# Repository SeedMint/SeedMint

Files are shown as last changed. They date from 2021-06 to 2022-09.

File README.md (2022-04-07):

# SeedMint
[DONATE](https://permissionlessstore.duckdns.org:57800/apps/4U7dYjY3Po74d5rREmCaG5ngVtTc/pos)

### INTRODUCTION

#### SEEDMINT is a FREE OPEN SOURCE HARDWARE (FOSH) Product.  
  
Technical drawings, material specifications and information regarding standard parts can be found in the designated folder.  
  
Adequate personal bitcoin security is a daunting challenge - one that will not forgive many mistakes. Every user’s situation regarding technical understanding and personal priorities, threat model and risk tolerance is fundamentally unique which renders generalized advice insufficient at best, dangerously confusing at worst.  
To achieve a level of security you can feel comfortable with you must find the right trade-off between cost, privacy, complexity, and failure tolerance.  
We cannot tell you what is best for your individual situation, but we can do our best to provide tools to aid you on your journey. The first of these tools is the SEEDMINT.
  
### PURPOSE
  
The SEEDMINT is a tool designed to easily secure your 12 or 24 bitcoin backup words (mnemonic seed phrase) on highly durable V4A stainless steel washers.
Using the included punches (4mm numbers & 2mm letters/numbers) you can stamp the index number (01 to 24) as well as the significant characters (first four letters) of each word onto one washer. This will result in 12 or 24 stamped washers.  
Additional washers can be stamped with any relevant information you would like to secure in combination with your seed. This additional information may include but is not limited to: master fingerprint, derivation path, wallet name, passphrase, multisig scheme,...  
  The stamped washers can be held on a 316L stainless steel screw, fastened by a self-locking nut and stored in a secure location as an ultimate backup.
The above description is the use case we envisioned as a basis for the design of the SEEDMINT and is merely a recommendation. At the end of the day, it is up to you which information you would like to stamp on the washers and how you choose to store them.

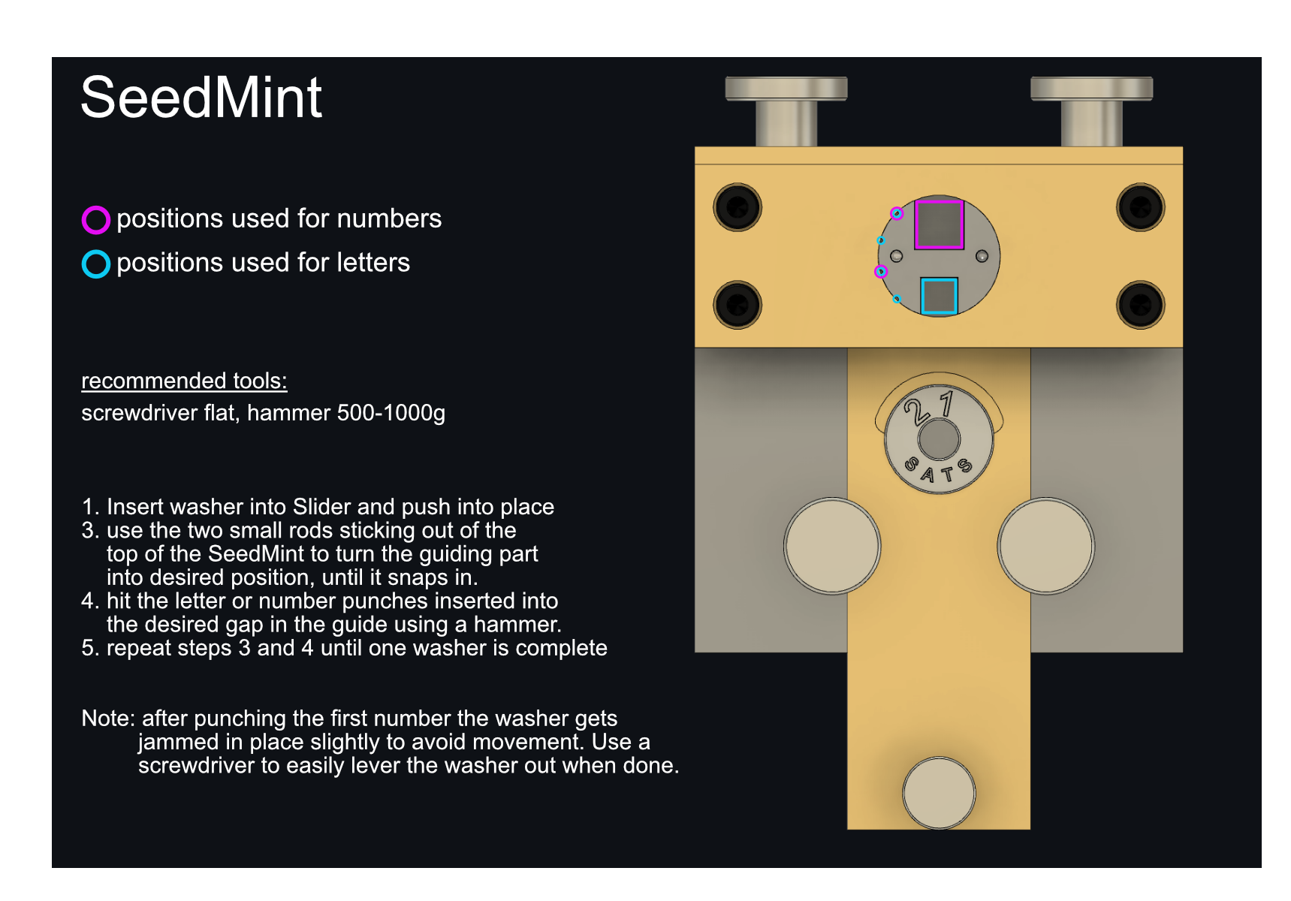
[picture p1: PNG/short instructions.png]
SeedMint


Click "view code" on the Top to see all files

In the [CAD](https://github.com/SeedMint/SeedMint/tree/main/CAD "Drawings and 3D Model") folder you find the complete design in different format types .zip for Inventor 2019 and .f3z for [Autodesk Fusion 360](https://www.autodesk.de/campaigns/education/fusion360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 "Autodesk Fusion 360") (which doesnt cost anything for personal use)

Here you find the [PDF](https://github.com/SeedMint/SeedMint/tree/main/PDF) drawings of the single pieces and a parts list.

This are links to the [letter](https://www.amazon.de/gp/product/B01BTTMEJU/ref=ppx_yo_dt_b_asin_title_o08_s00?ie=UTF8&psc=1) and [number](https://www.amazon.de/Turnus-330-004-TURNUS-0007697220004-Schlagbuchstaben-Nummern/dp/B00D17RJ7Q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) stamps used in the current Design

Parts to buy: (just paste the description into a search engine to find local sources)

<table>
  <thead>
    <tr>
      <th>Amount</th>
      <th>Description</th>     
    </tr>
  </thead>
  <tbody>
    <tr>
      <td>4</td>
      <td>cylinder head screw DIN 912 M4x20</td>    
    </tr>
    <tr>
      <td>2</td>
      <td>flat knurled screw M4x10</td>
    </tr>
     <tr>
      <td>2</td>
      <td>high knurled screw M5X12</td>
    </tr>
     <tr>
      <td>2</td>
      <td>parallel pin ISO 8734 2m6x20 blank</td>
        <tr>
      <td>1</td>
      <td>high knurled screw M3 (thread shortened)</td>
    </tr>
     <tr>
      <td>1</td>
      <td>spring plunger with thread locking GN 615.3-M4-k-PFB</td>
    </tr>
     <tr>
      <td>1</td>
      <td>parallel pin ISO 8734 3m6x12 blank</td>
    </tr>
     <tr>
      <td>min. 24</td>
      <td>washer DIN 9021 6.4 A4(316L) or titanium grade 2</td>
    </tr>
     <tr>
      <td>1 set</td>
      <td>number punches 4mm</td>
    </tr>
     <tr>
      <td>1 set</td>
      <td>letter punches 2mm</td>
    </tr>
  </tbody>
</table>

The "original" **SeedMint** was tinkered without any references or drawings at all. Just for the love of handcrafiting things that I consider useful.
But only after somebody asked me, if i would make plans for such a Jig available,  so I thought if only one person would get value from this, it would have been worth while making those plans. This has also been the first time I have heared about [Blockmit](https://blockmit.com/english/guides/diy/make-cold-wallet-washers/ "blockmit.com") - quite ignorant as I'll admit..

The Jig is intended to be used with 2-3mm letter- and 4mm number punches on an M6 stainless steel washer with an outer diameter of 18mm.
Just use a screw and a nut to hold them together.
More solutions will follow.

Any contribution and/or feedback is greatly appreciated.

follow us [@SeedMint21](https://twitter.com/SeedMint21) on twitter for updates 
<!--
**SeedMint/SeedMint** is a ✨ _special_ ✨ repository because its `README.md` (this file) appears on your GitHub profile.

Here are some ideas to get you started:

- 🔭 I’m currently working on ...
- 🌱 I’m currently learning ...
- 👯 I’m looking to collaborate on ...
- 🤔 I’m looking for help with ...
- 💬 Ask me about ...
- 📫 How to reach me: ...
- 😄 Pronouns: ...
- ⚡ Fun fact: ...
-->

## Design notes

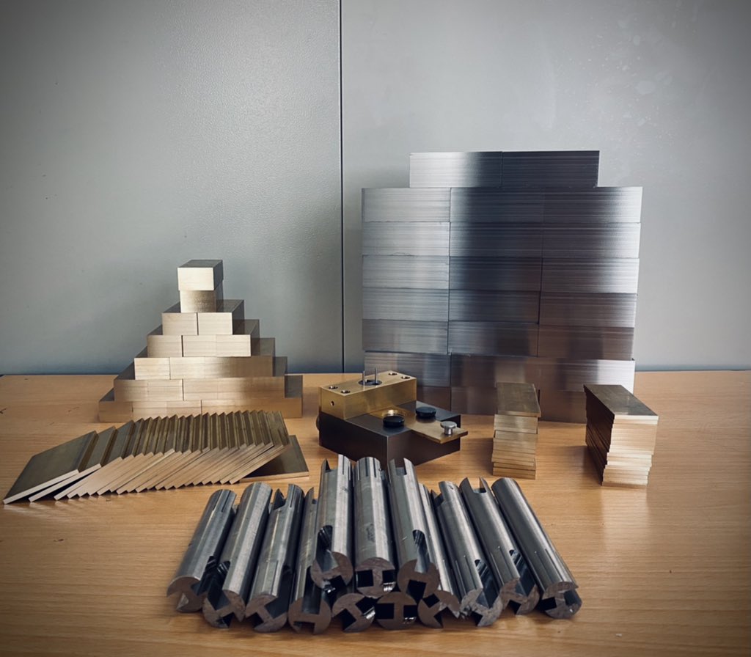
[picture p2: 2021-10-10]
PNG/4161E84F-398B-41A6-904F-D0B08AE500F2.jpeg

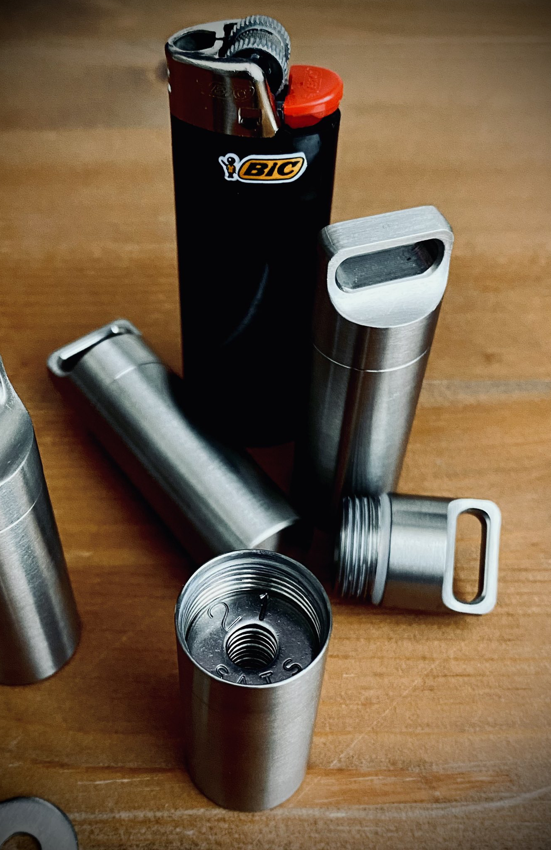
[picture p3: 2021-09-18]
PNG/pill.jpg

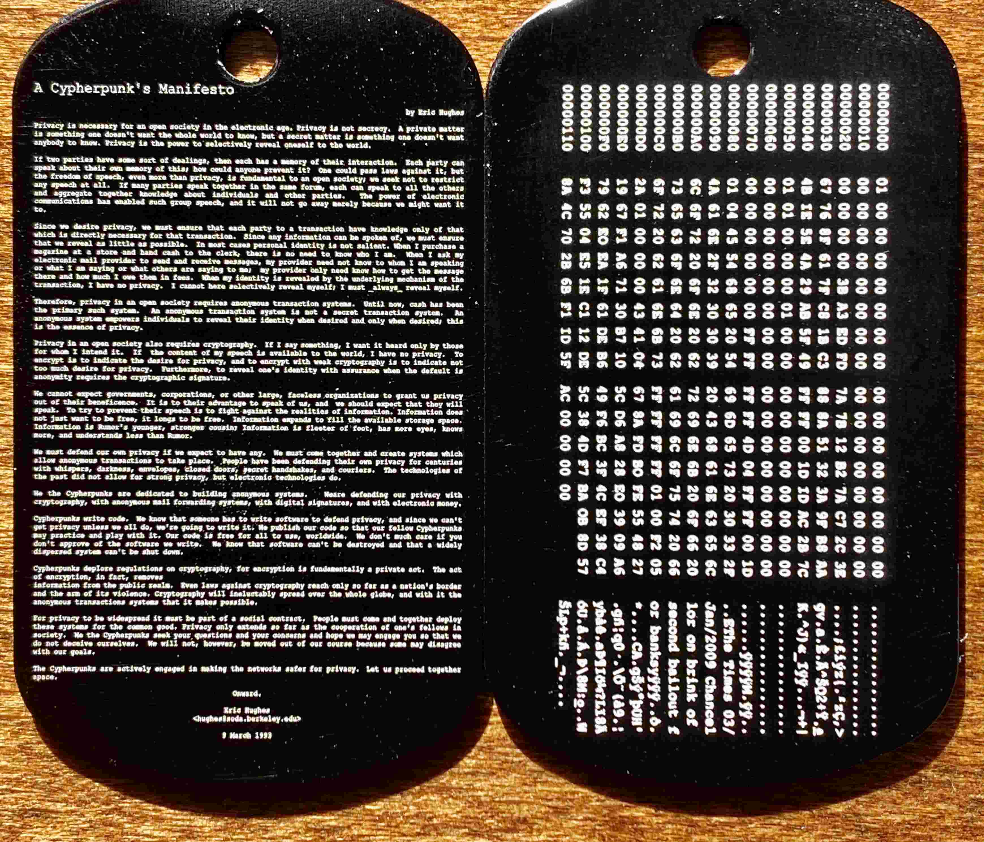
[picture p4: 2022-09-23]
PNG/manifesto_genesis.jpg

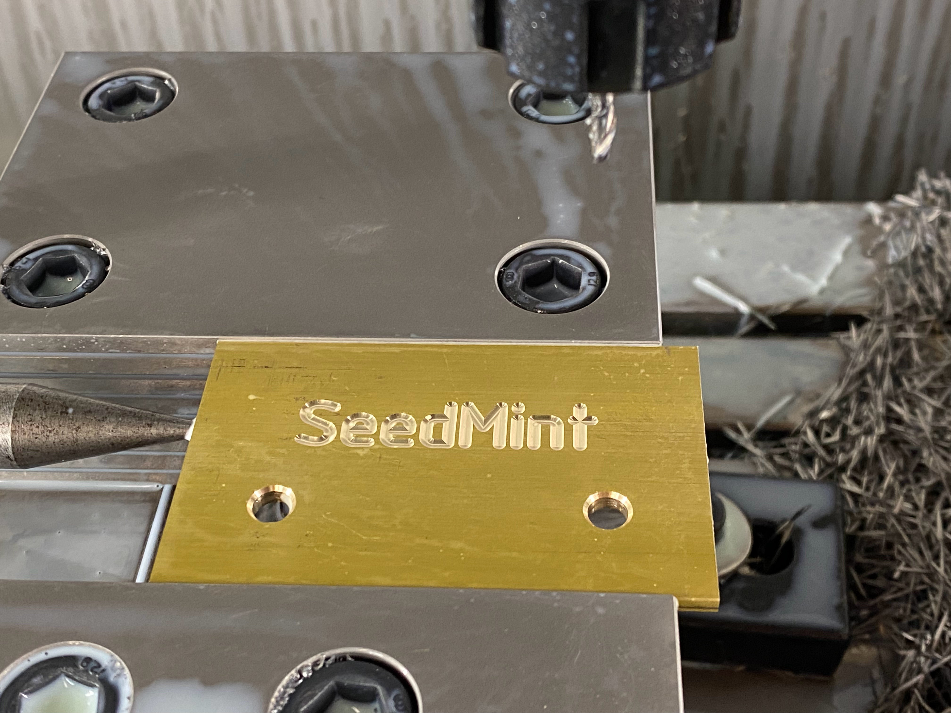
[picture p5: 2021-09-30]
PNG/FP.jpg

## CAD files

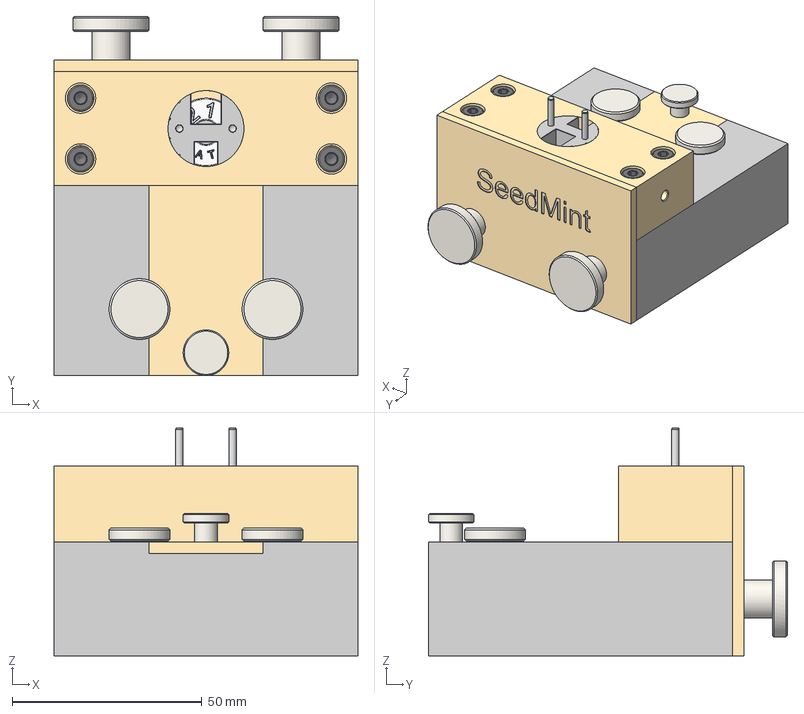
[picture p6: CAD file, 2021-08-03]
CAD/SeedMint Assembly.step
80.0 x 94.5 x 60.0 mm
Faceplate
Base
Slider
Retainer
Guide
HI_WUERTH 00824 20 cylinder head screw DIN 912 M4x20 8.8 BLK x 4
_Knurled screw DIN 464-M3-6-ZB
_Flat knurled screw DIN 653-M4-10-ZB x 2
_Knurled screw DIN 464-M5-12-ZB x 2
parallel pin ISO 8734 3m6x12 blank
parallel pin ISO 8734 2m6x20 Blank x 2
Spring plunger with thread locking GN 615.3-M3-K-PFB
washer DIN 9021 6.4 A4

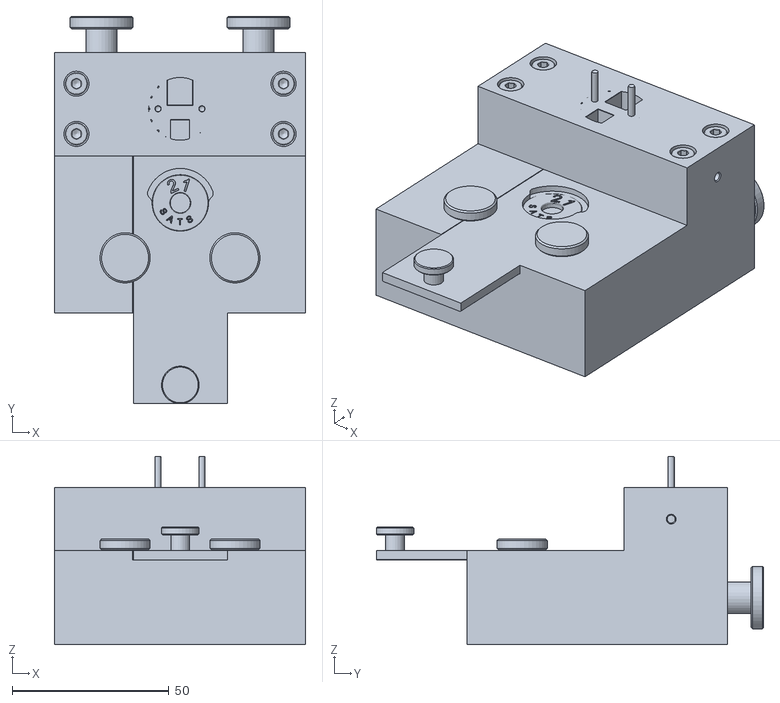
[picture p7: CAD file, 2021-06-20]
CAD/SeedMint.stl
80.0 x 123.5 x 60.0

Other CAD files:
CAD/Assembly v1.dwg
CAD/Base Drawing a3 v1.dwg
CAD/Slider Drawing A3 for CNC v1.dwg
CAD/Guide Drawing A4 v1.dwg
CAD/Faceplate Drawing A3 v1.dwg
CAD/Retainer Drawing A3 v1.dwg
CAD/SeedMint assembly.f3z

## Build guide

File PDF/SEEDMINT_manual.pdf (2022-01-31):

# SEEDMINT

## MANUAL

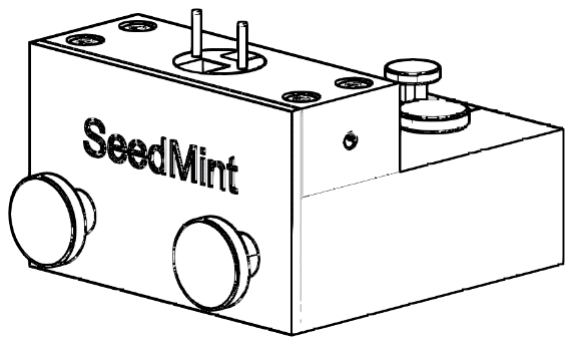
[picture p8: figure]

- 1 -

### CONTENT

INTRODUCTION | 2-3
PURPOSE | 4-5
PACKAGE CONTENT | 6
SEEDMINT - PART LIST | 7-10
ASSEMBLY | 11-12
HANDLING | 13-16
CARE | 17-18
PRIVACY POLICY | 19
CONTACT | 20 - 23

- 2 -

### INTRODUCTION

This is a 100% private offering. No safety labels, no security checks, no warranty, no refund, no guarantees - just two plebs' word.

SEEDMINT is a FREE OPEN SOURCE HARDWARE (FOSH) Product published under the MIT license. Technical drawings, material specifications and information regarding standard parts as well as this manual can be found at:

https://github.com/SeedMint

- 3 -

Adequate personal bitcoin security is a daunting challenge - one that will not forgive many mistakes. Every user’s situation regarding technical understanding and personal priorities, threat model and risk tolerance is fundamentally unique which renders generalized advice insufficient at best, dangerously confusing at worst.

To achieve a level of security you can feel comfortable with you must find the right trade-off between cost, privacy, complexity, and failure tolerance.

We cannot tell you what is best for your individual situation, but we can do our best to provide tools to aid you on your journey. The first of these tools is the SEEDMINT.

- 4 -

### PURPOSE

The SEEDMINT is a tool designed to easily secure your 12 or 24 bitcoin backup words (mnemonic seed phrase) on highly durable V4A stainless steel washers.

Using the included punches (4mm numbers & 2mm letters/numbers) you can stamp the index number (01 to 24) as well as the significant characters (first four letters) of each word onto one washer. This will result in 12 or 24 stamped washers.

Additional washers can be stamped with any relevant information you would like to secure in combination with your seed. This additional information may include but is not limited to: seed creation date, seed creation block hight, master fingerprint,

- 5 -

derivation path, wallet name, passphrase, multisig scheme, or xpub. The stamped washers can be held on a V4A stainless steel screw, fastened by a self-locking nut (included in the package) and stored in a secure location as an ultimate backup.

The above description is the use case we envisioned as a basis for the design of the SEEDMINT and is merely a recommendation. At the end of the day, it is up to you which information you would like to stamp on the washers and how you choose to store them.

- 6 -

### PACKAGE CONTENT

1x | SEEDMINT
1x | Set of 4mm number punches
1x | Set of 2mm number punches
1x | Set of 2mm letter punches
1x | Silicon oil 65ml
210x | M6 V4A stainless steel washers
3x | M6x60 V4A stainless steel screws
3x | M6x30 V4A stainless steel screws
6x | M6 V4A stainless steel self-locking bolt

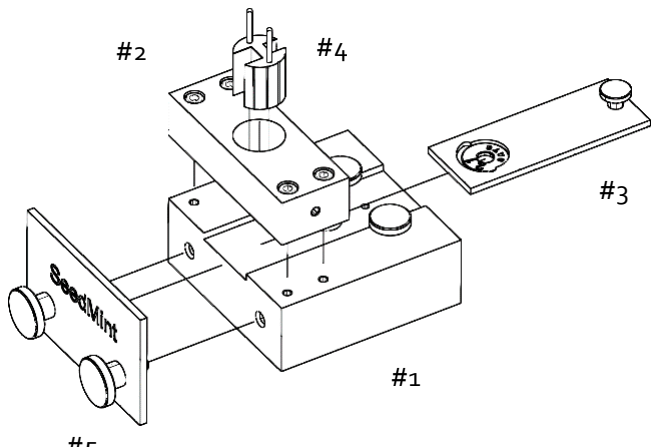
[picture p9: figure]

- 7 -

### SEEDMINT - PART LIST

Milled parts:
#1 BASE

#2 RETAINER

#3 SLIDER

#4 GUIDE

#5 FACEPLATE

#5

- 8 -

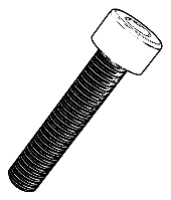
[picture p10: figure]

Standard parts:
4x | Cylinder head screw DIN 912 M4x20

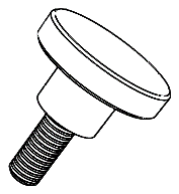
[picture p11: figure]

2x | Flat knurled screw M4x10
2x | High knurled screw M5X12

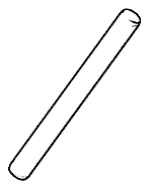
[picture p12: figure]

2x | Parallel pin ISO 8734 2m6x20 blank

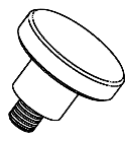
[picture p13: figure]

1x | High knurled screw M3 (shortened)

- 9 -

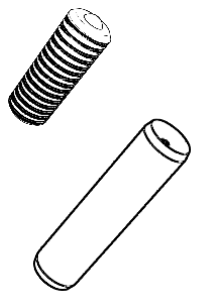
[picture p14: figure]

1x | Spring plunger with thread locking GN615.3-M4-k-PFB
1x | Parallel pin ISO 8734 3m6x12 blank

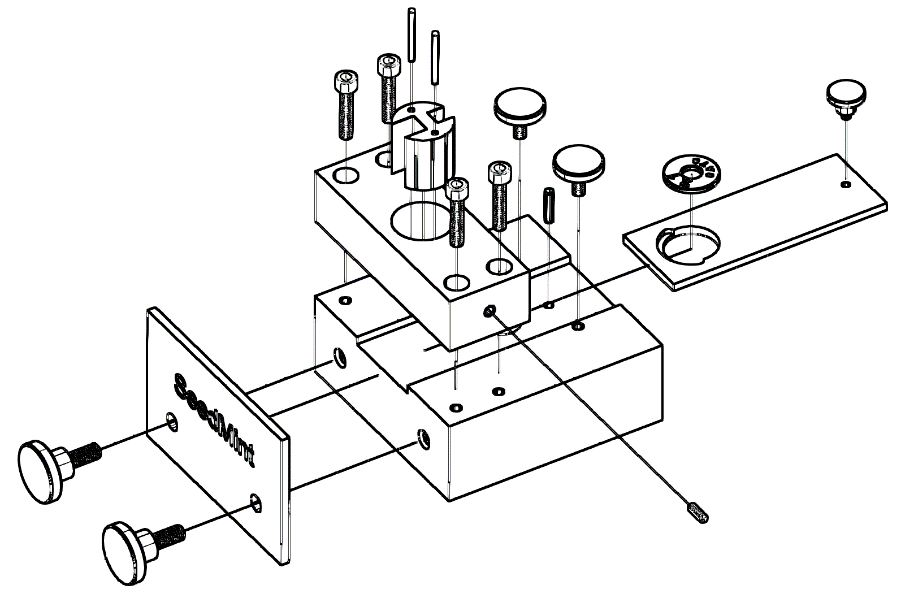
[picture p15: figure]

- 10

- 11 -

### ASSEMBLY

The SEEDMINT will be shipped in a semi-assembled state. The GUIDE is separate within the package. Place the SEEDMINT on a flat surface and insert the GUIDE into the central hole in the RETAINER with the larger cut-out facing left and the two pins facing upwards. After inserting the GUIDE slowly turn it clockwise by applying light torque to the two pins. You will feel four rachet positions while turning 180°. These are the four 4mm and four 2mm defined stamping positions visualized on the next page.

Check that all knurled screws are securely fastened.

Your SEEDMINT is now ready for use.

- 12 -

Stamping positions:

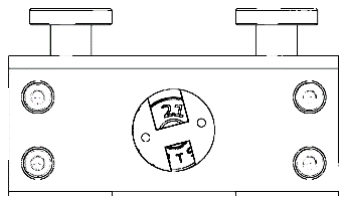
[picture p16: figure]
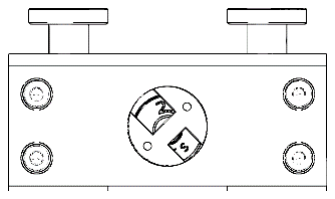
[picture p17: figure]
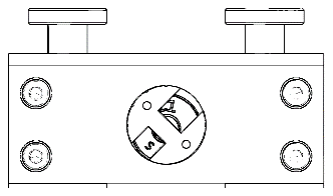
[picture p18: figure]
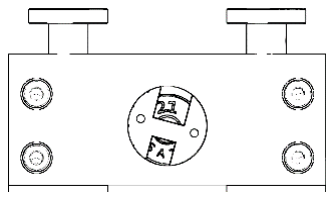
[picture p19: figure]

Deviating from these four positions is possible for a custom layout but not advised for accurately reproducible results.

2 Pos. 1 | Pos. 2
Pos. 3 | Pos. 4

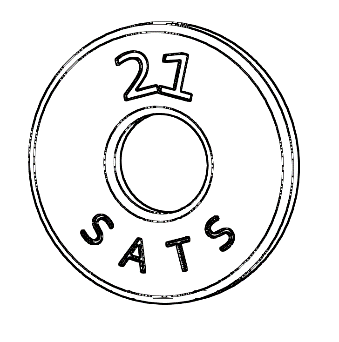
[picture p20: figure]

- 13 -

### HANDLING

Let’s start off with a test run: this is what the test washer will look like if we were successful in writing a comprehensive manual:

1. Before you start you will need a firm, flat surface to place your SEEDMINT on, a hammer, as well as all parts included in the package.

- 14 -
2. You can start by pulling back the SLIDER and inserting a washer with the rounded edges facing upwards. By pushing the SLIDER back under the RETAINER, the washer will be correctly positioned under the GUIDE.
3. Rotate the GUIDE to position 2 and insert the number “2” 4mm punch into the large cut-out (if you would prefer the numbers to be stamped with a small offset you can also choose position 1 instead).
4. Rest the palm of your left hand (right if you are lefthanded) on the knurled screw on the SLIDER to ensure the SLIDER does not move and stabilize the punch between your thumb and forefinger. Push the punch down against the washer.
5. Now the moment you have been waiting for: We know you really want to WHACK IT but start off with moderate force.

- 15 -

NOTE: It is not advised to stamp the same character twice in the same position on the same washer as this can damage the punches. If you are not happy with the level of penetration you can crank it up on the next washer.

6. Extract the punch and rotate the GUIDE into position 3 and repeat as from bullet point 4. Using the number “1” 4mm punch.
7. Once the index number is stamped, extract the punch, rotate the GUIDE to position 4, insert the first 2mm letter punch “S” and hit it.
8. Positions 3, 2, 1 follow with the 2mm letter punches “A”, “T”, “S” respectively.
9. Pull back the SLIDER and retrieve the washer using a flat headed screwdriver or just flipping the SEEDMINT on its head.
10. Congrats, your first stamped washer is complete!

- 16 -

After you’ve stamped a few washers, you’ll get a feel for the process and start to produce consistent results. Once you feel comfortable it’s time to start with an actual seed. For this you can either retrieving a backup of an old seed or securely create a new one and write it down on a piece of paper with the index numbers leading each word. Take the time to double check each word!

01 | ACTION | [...]
02 | BOSS | 23 | WILL
[...] | | 24 | WISH
11. Write down all information you’d like to stamp additionally.
12. Be diligent and perfectionistic about your work. You’ll thank yourself later.

- 17 -

### CARE

The SEEDMINT is a tool, no doubt about it. Beautiful, absolutely, but made to be used. She likes it rough, but she’ll need some love and care along the way.

To prevent highly oxidated surfaces and ensure ease of use you should store the SEEDMINT in a dry environment.

Included in the package is a bottle of silicon oil. Before first use after a long time in storage, apply a thin oil film to the contact surfaces between the GUIDE and the RETAINER using a cotton cloth.

A spring plunger is screwed into the RETAINER to provide defined stamping positions to the GUIDE. We carefully adjusted the plunger during assembly to apply the correct amount of force for an easy

- 18 -

but well-defined feel. The correct position over time was ensured by using thread locking glue (LOCTITE 243). At some point you may have to readjust the plunger if the pressure becomes too weak.

With every misguided hammer stroke and every careless contact with another hard object or just with every year that passes by, your SEEDMINT will inevitably gain scars. We always design our products to make form follow function. Because of this the functionality of your SEEDMINT will not be impaired by scratches, dents, or tinted metal surfaces. Depending on your preferences you can chose to polish up the brass with some fine polish past and a cotton cloth to regain that nice and bright new look. We personally prefer our SEEDMINT to have some character and proudly display its history. Your call.

- 19 -

### PRIVACY POLICY

We are highly focused on trying to minimize the amount of personal customer data we collect. The following data is unfortunately needed:

At purchase:
- Email address
Once package is ready to be shipped:
- Name and shipping address

All your personal information will be deleted once shipping is complete unless you actively ask us to save your data.

For more details on future customer verification please read section “CONTACT”.

- 20 -

### CONTACT

In case you have any questions, requests or feedback please do not hesitate to reach out. We are designing all our products for the community just as much as for ourselves. We deeply care about your thoughts regarding our designs as well as our service as we are convinced that we can do nothing but improve through engagement with our community.

As we have set our default policy to delete all personal customer information once the package has arrived, we have included a code in your package which you can provide when contacting us to prove you are a customer.

- 21 -

As a FOSH project we are committed to an open standard with a transparent design process under a permissionless licence. To further drive this project, we are hugely thankful if you consider supporting us:

donate.seedmint21.com

We would love to welcome you to join the customer exclusive chat group “SeedMint Family”:
- Telegram: t.me/+96MqXO-jKb1kZWYy

As well as our public group “SeedMint Community”:
- Telegram: t.me/SeedMint21

- 22 -

You can contact us via:
- Email: | seedmint21@protonmail.com
- Twitter: | @SeedMint21
| @snicktoshi
| @antomousB
- Telegram: @SeedMint21

Find all our products at:
| store.seedmint21.com

Stay up to date on all future products & developments:
- Twitter: @seedmint21

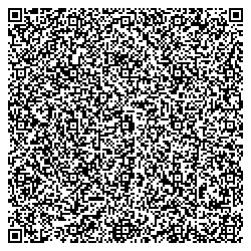
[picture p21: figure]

- 23 -

We will gladly send you our PGP public key if you shoot us a quick message. Alternatively, you can scan the following QR-code containing our key:

- 24 -

WE TRULY APPRECIATE YOU.

PERSONAL RESPONSIBILITY.
ONE SEED AT A TIME.

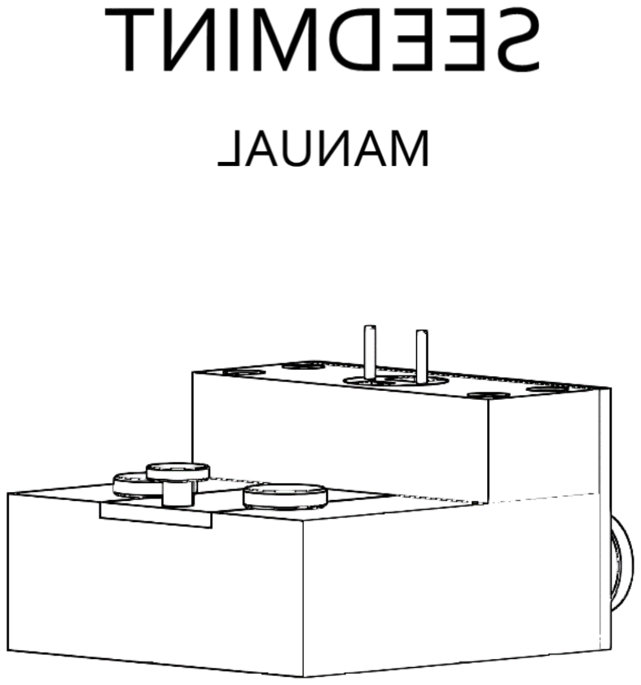
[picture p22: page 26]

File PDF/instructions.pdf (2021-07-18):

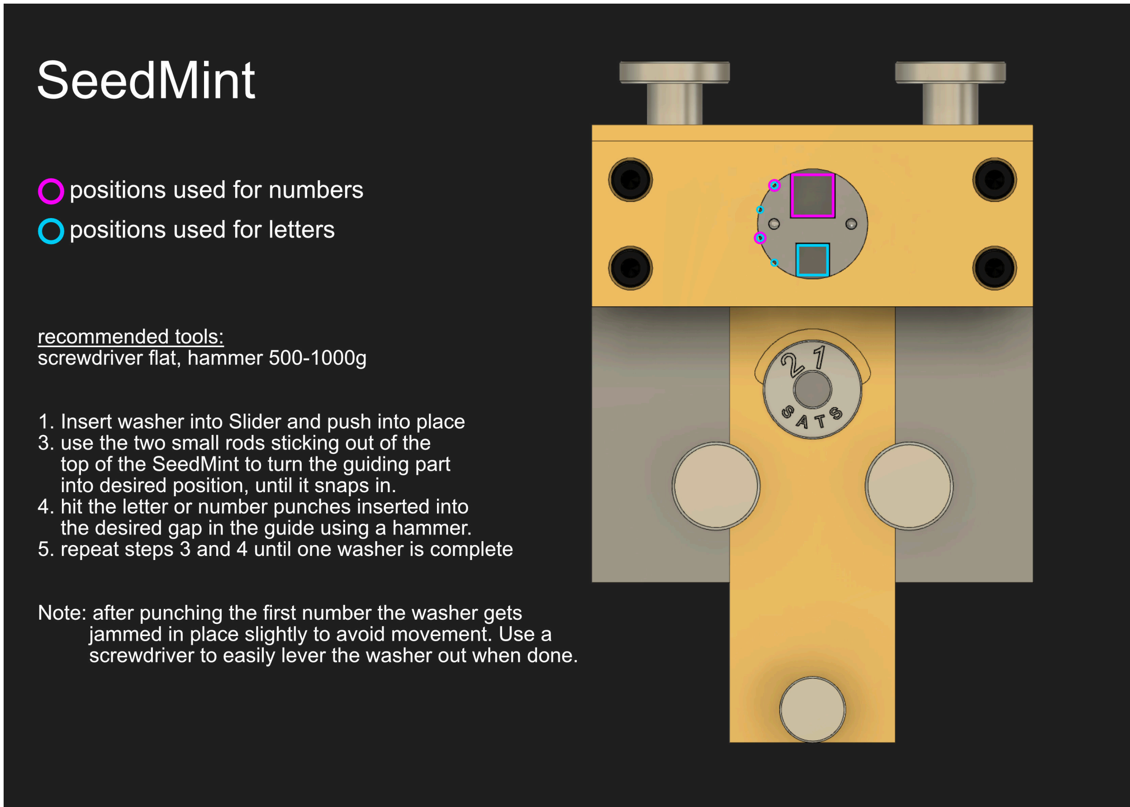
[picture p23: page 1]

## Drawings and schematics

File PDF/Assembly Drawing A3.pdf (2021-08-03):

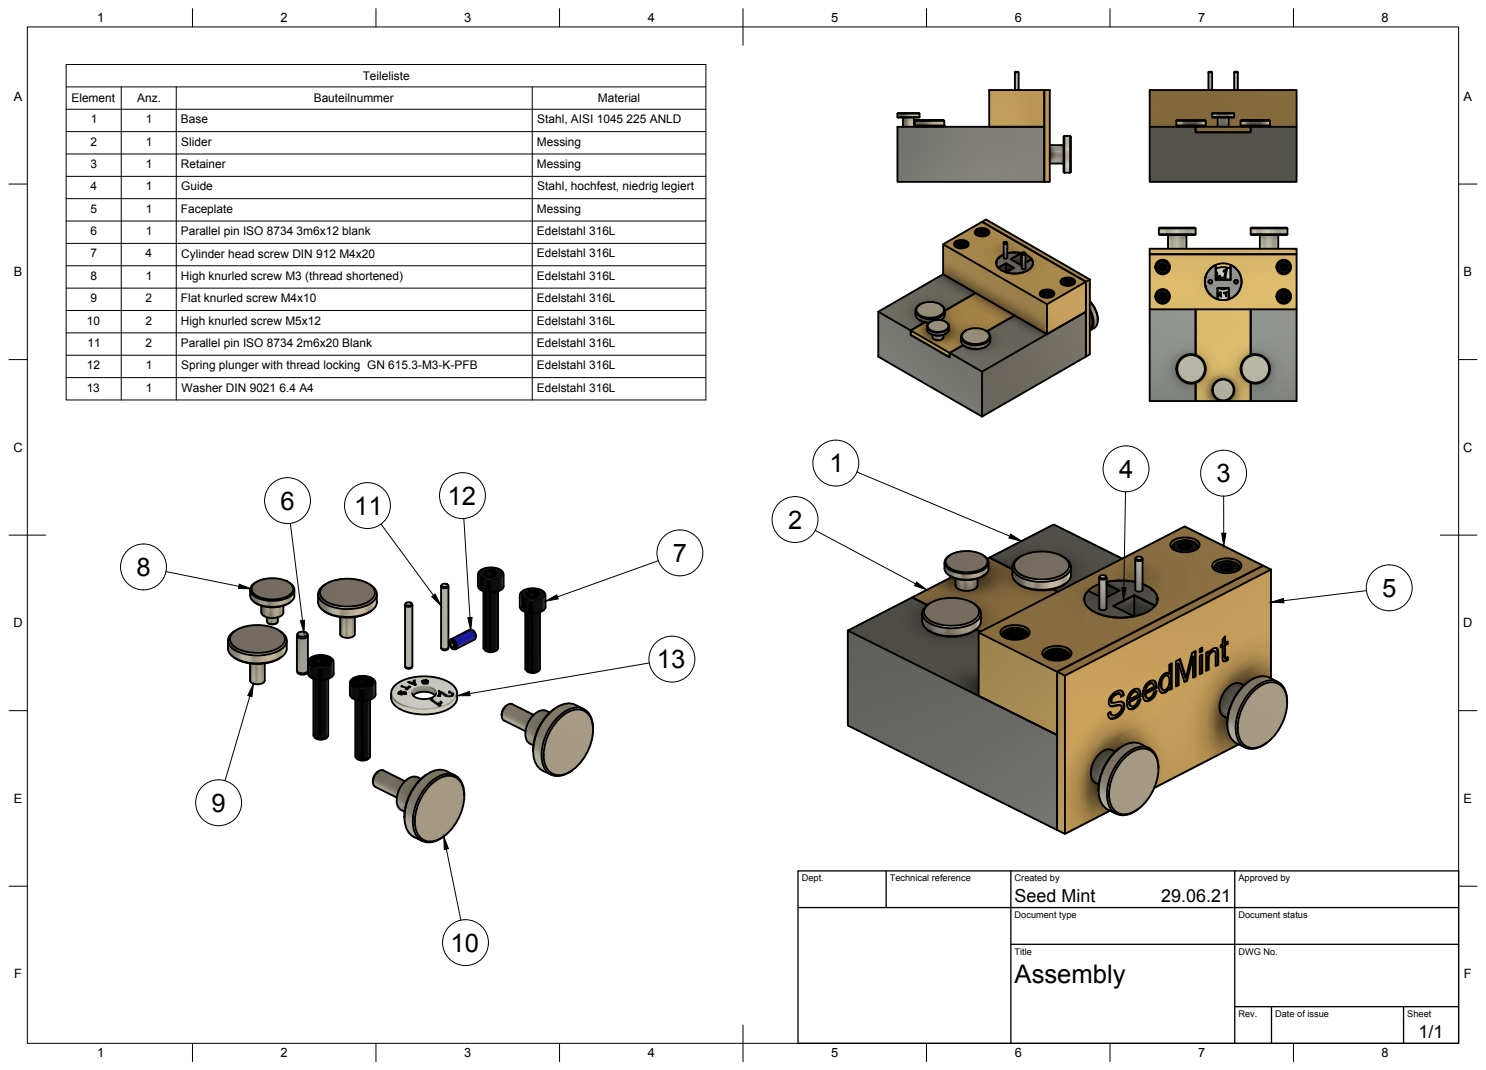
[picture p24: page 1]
Title; DWG No.; Rev.; Date of issue; Sheet

Element | Anz. | Bauteilnummer | Material

1 | 1 | Base | Stahl, AISI 1045 225 ANLD

2 | 1 | Slider | Messing

3 | 1 | Retainer | Messing

4 | 1 | Guide | Stahl, hochfest, niedrig legiert

5 | 1 | Faceplate | Messing

6 | 1 | Parallel pin ISO 8734 3m6x12 blank | Edelstahl 316L

7 | 4 | Cylinder head screw DIN 912 M4x20 | Edelstahl 316L

8 | 1 | High knurled screw M3 (thread shortened) | Edelstahl 316L

9 | 2 | Flat knurled screw M4x10 | Edelstahl 316L

10 | 2 | High knurled screw M5x12 | Edelstahl 316L

11 | 2 | Parallel pin ISO 8734 2m6x20 Blank | Edelstahl 316L

12 | 1 | Spring plunger with thread locking GN 615.3-M3-K-PFB | Edelstahl 316L

13 | 1 | Washer DIN 9021 6.4 A4 | Edelstahl 316L

Dept. | Technical reference | Created by Seed Mint 29.06.21 | Approved by

Document type | Document status

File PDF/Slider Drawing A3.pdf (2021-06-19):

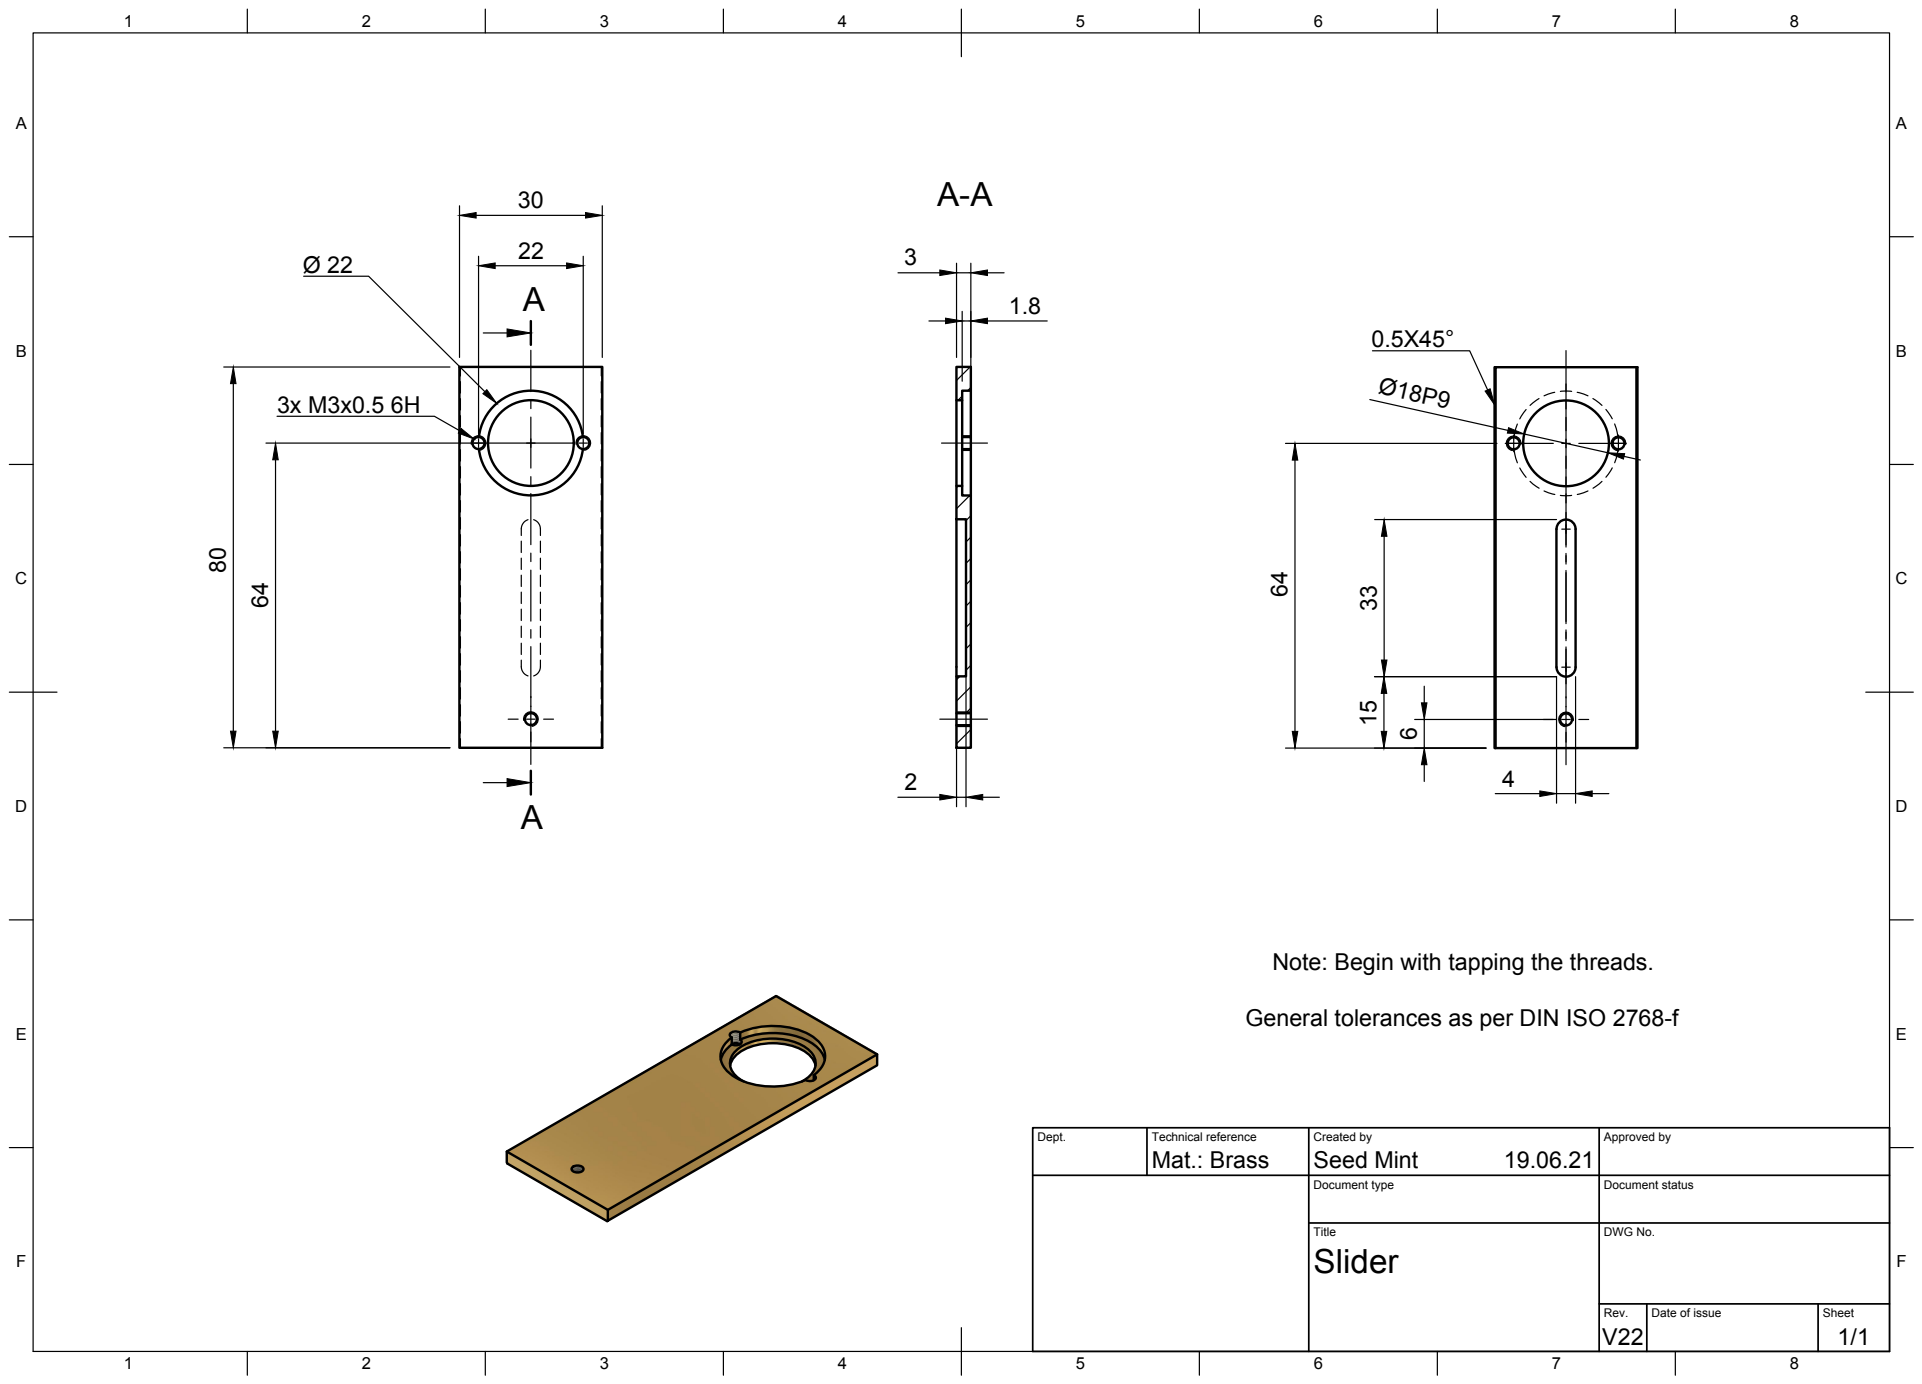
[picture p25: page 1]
Title; DWG No.; Rev.; Date of issue; Sheet

Note: Begin with tapping the threads.

General tolerances as per DIN ISO 2768-f

Dept. | Technical reference Mat.: Brass | Created by Seed Mint 19.06.21 | Approved by

Document type | Document status

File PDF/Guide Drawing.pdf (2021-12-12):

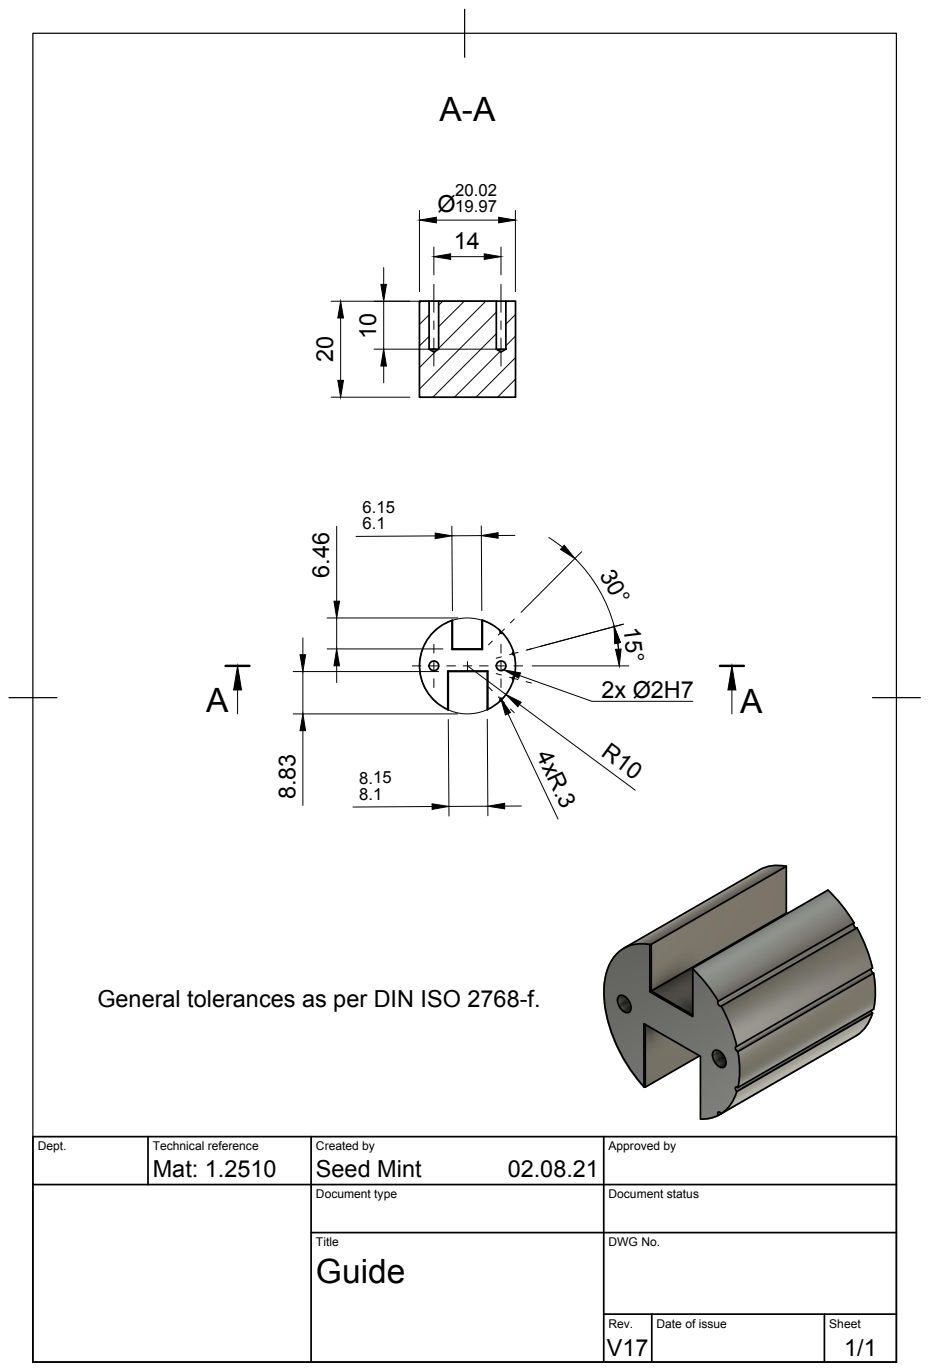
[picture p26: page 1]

General tolerances as per DIN ISO 2768-f.

Dept. | Technical reference Mat: 1.2510 | Created by Seed Mint 02.08.21 | Approved by

Document type | Document status

Title Guide | DWG No.

Rev. V17 | Date of issue | Sheet 1/1

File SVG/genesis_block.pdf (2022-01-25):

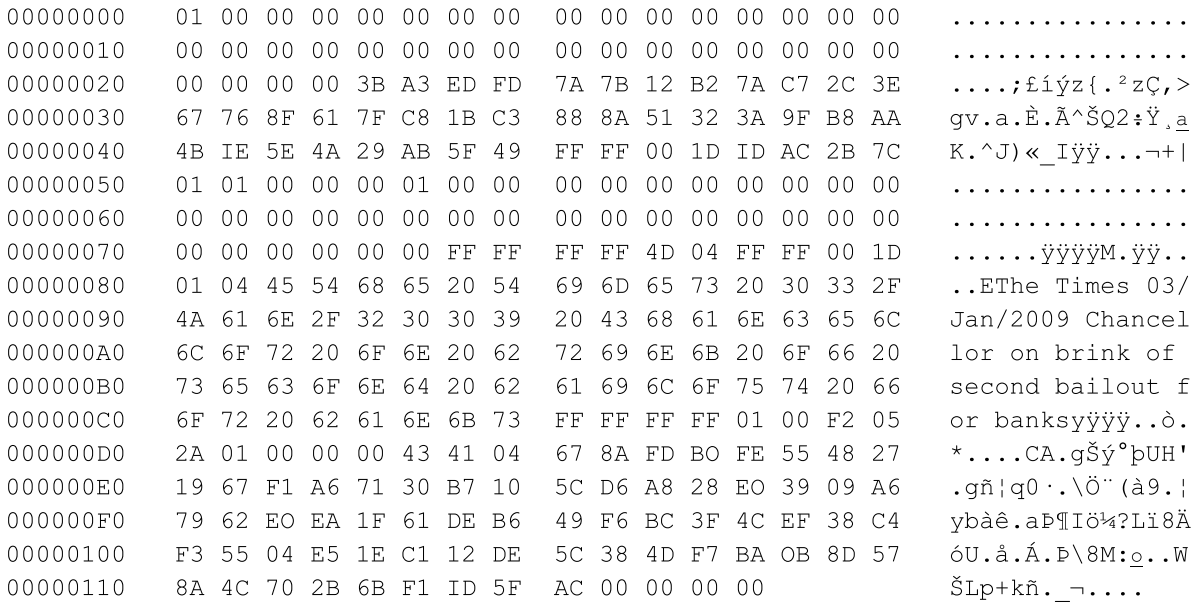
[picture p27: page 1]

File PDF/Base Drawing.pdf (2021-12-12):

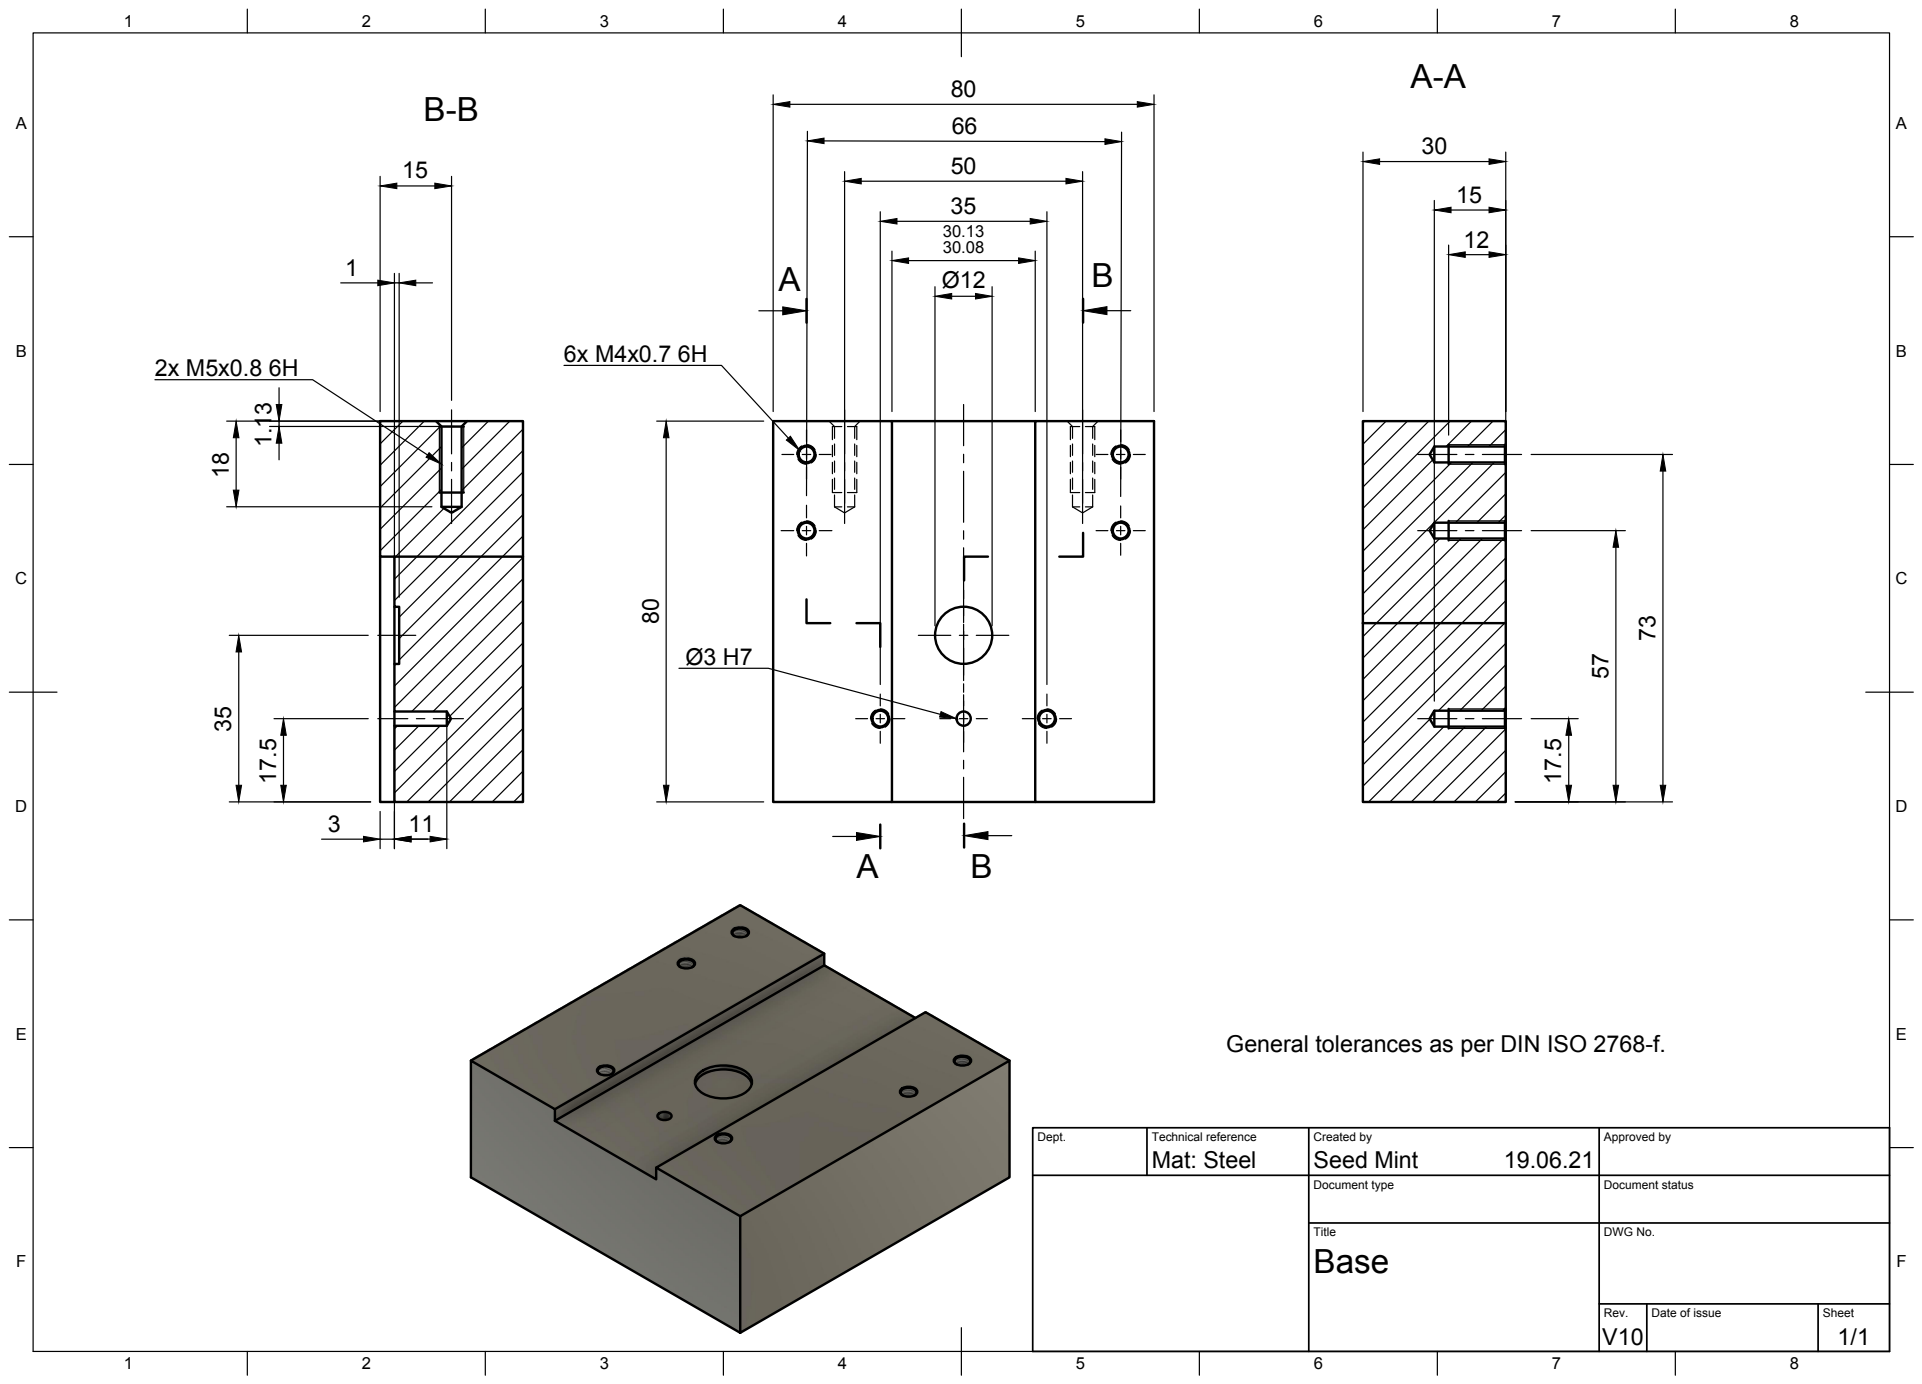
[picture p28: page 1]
Title; DWG No.; Rev.; Date of issue; Sheet

General tolerances as per DIN ISO 2768-f. 1.13

Dept. | Technical reference Mat: Steel | Created by Seed Mint 19.06.21 | Approved by

Document type | Document status

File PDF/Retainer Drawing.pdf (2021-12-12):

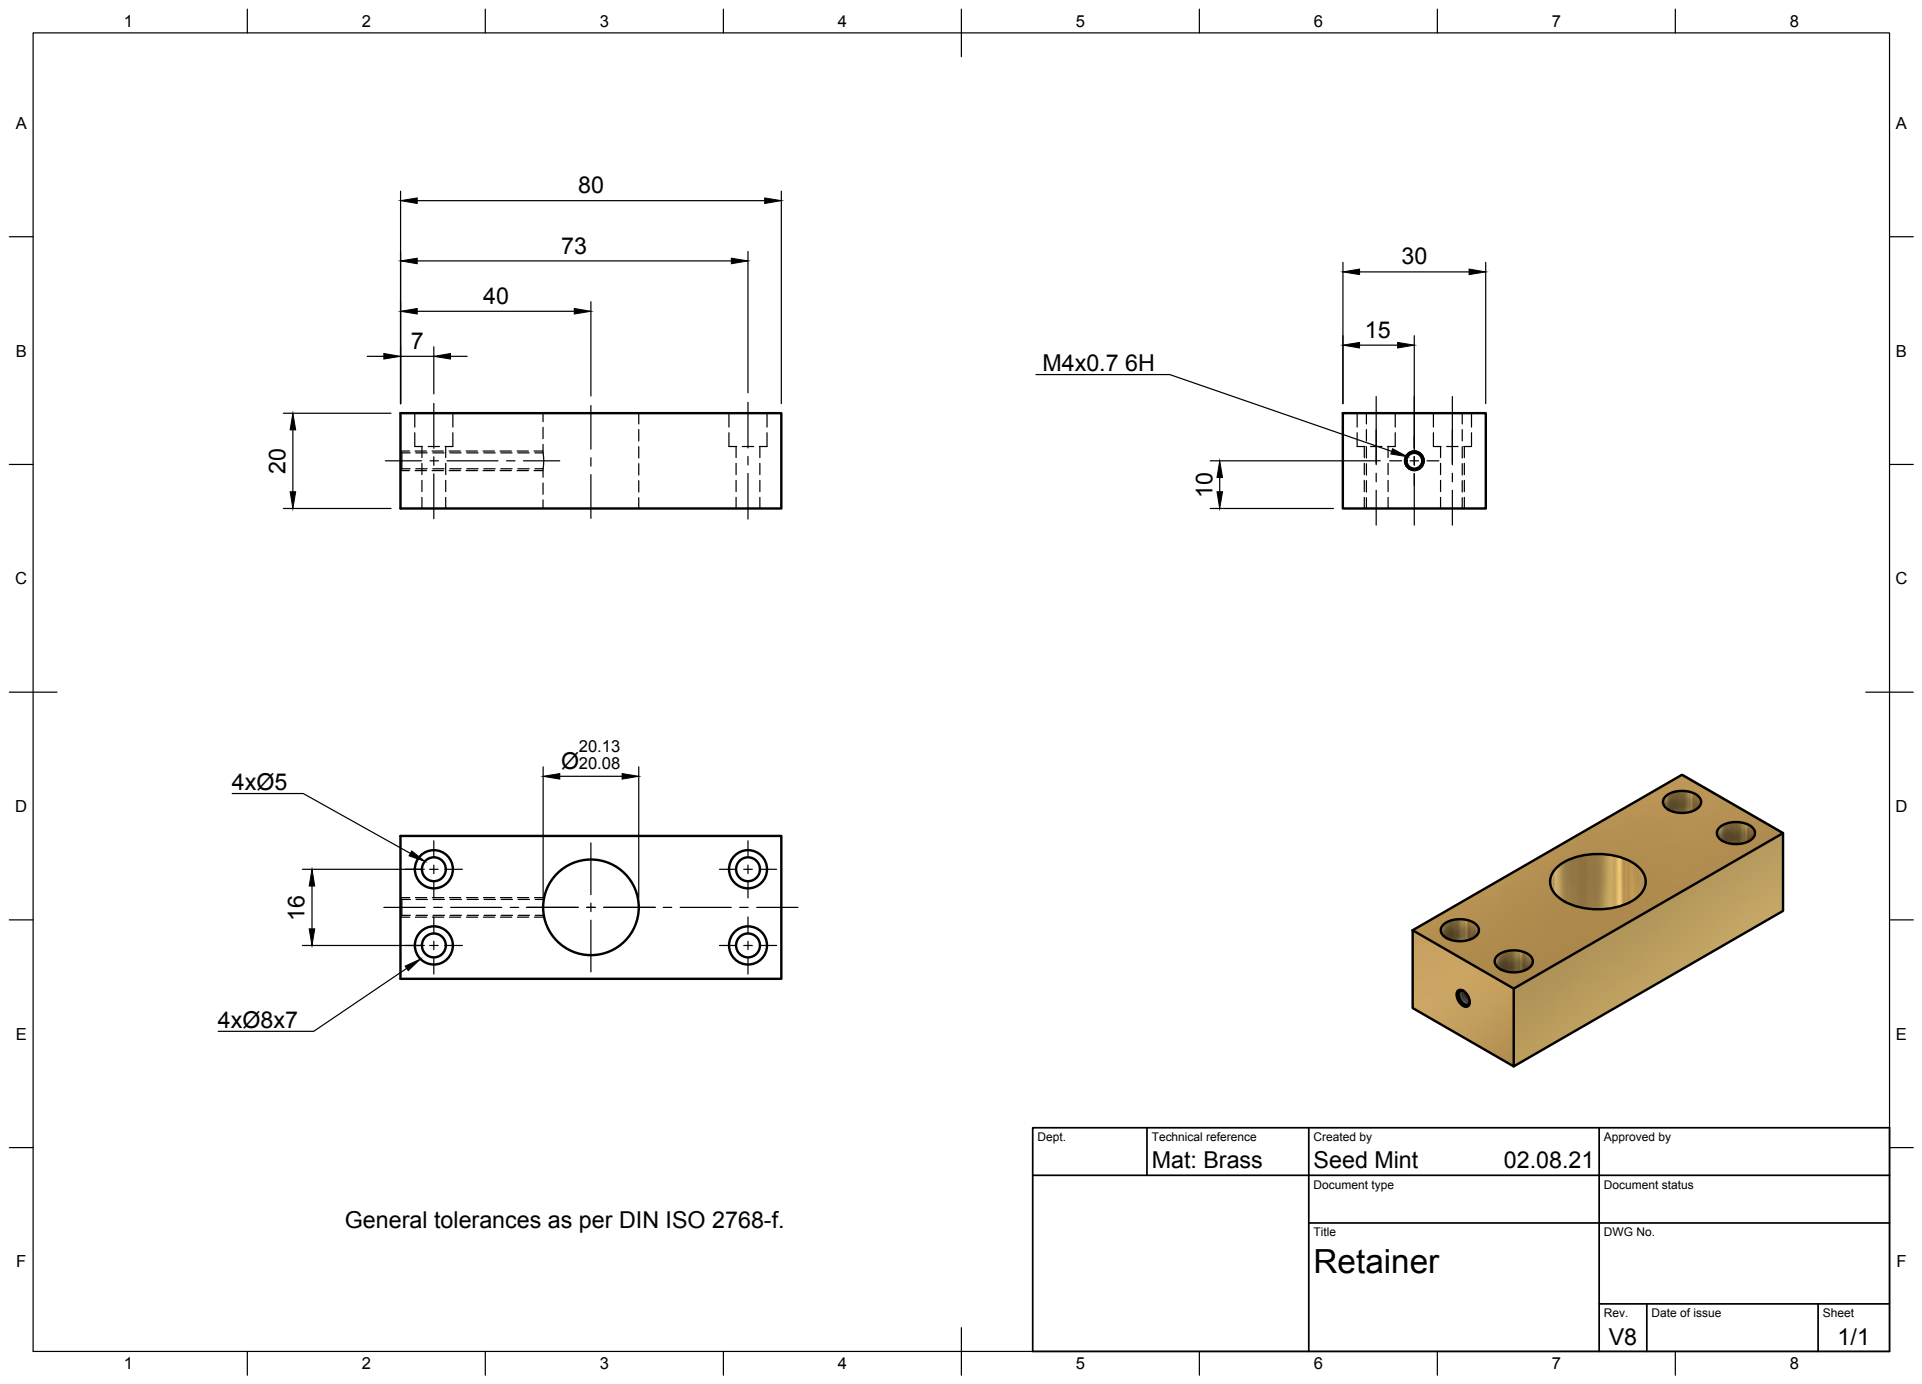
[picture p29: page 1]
Title; DWG No.; Rev.; Date of issue; Sheet; Mat: Brass; Seed Mint 20

General tolerances as per DIN ISO 2768-f. 16

Dept. | Technical reference | Created by 02.08.21 | Approved by

Document type | Document status

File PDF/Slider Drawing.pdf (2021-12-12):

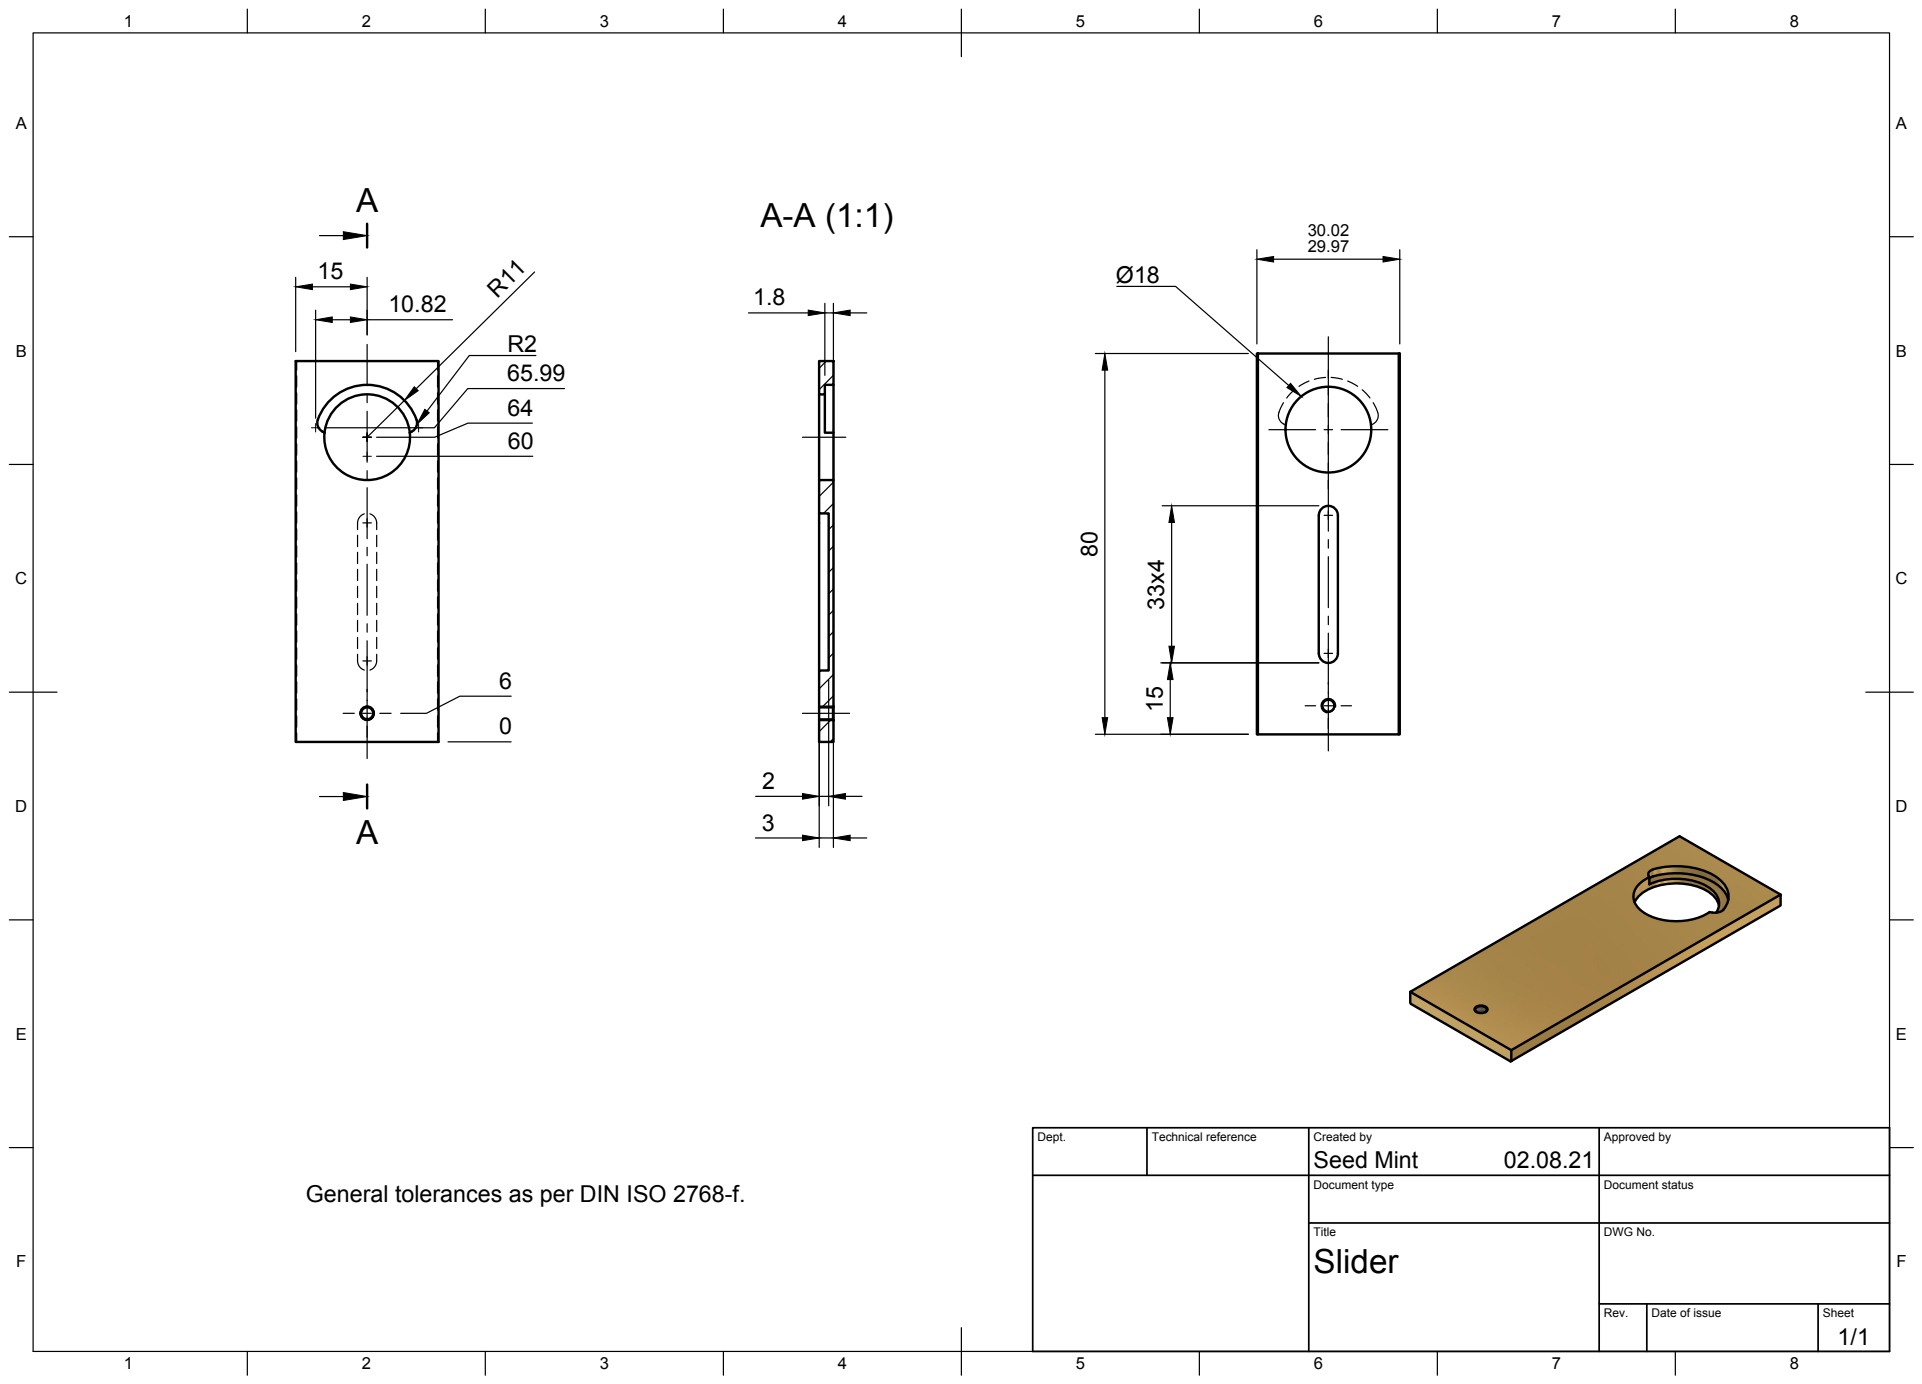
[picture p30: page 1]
Title; DWG No.; Rev.; Date of issue; Sheet

Dept. | Technical reference | Created by Seed Mint 02.08.21 | Approved by

General tolerances as per DIN ISO 2768-f.

Document type | Document status

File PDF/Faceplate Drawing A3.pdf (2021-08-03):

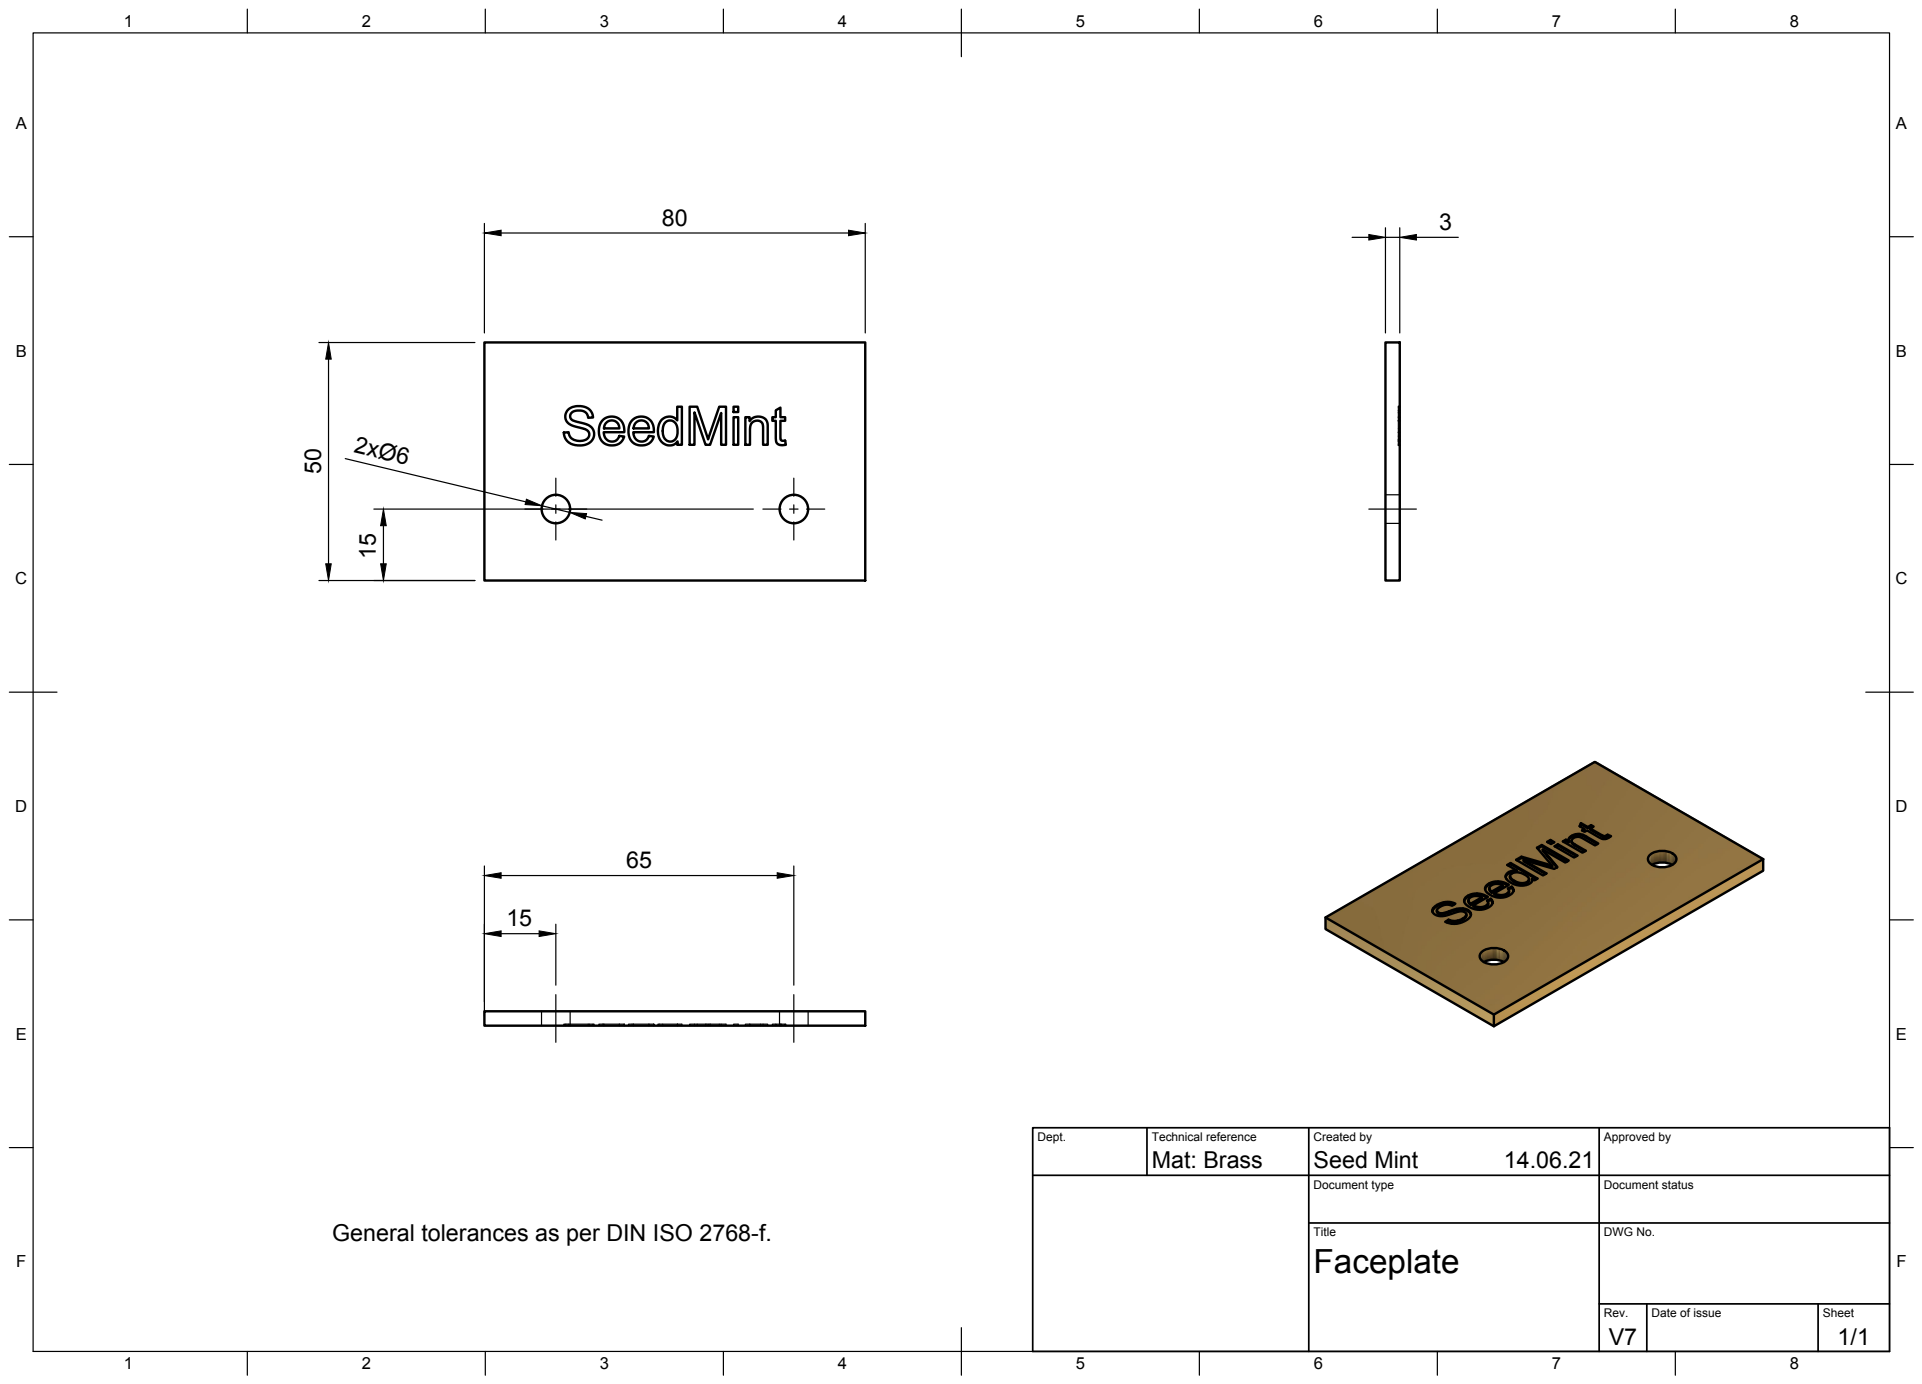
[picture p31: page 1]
Title; DWG No.; Rev.; Date of issue; Sheet

Dept. | Technical reference Mat: Brass | Created by Seed Mint 14.06.21 | Approved by

Document type | Document status

General tolerances as per DIN ISO 2768-f.
